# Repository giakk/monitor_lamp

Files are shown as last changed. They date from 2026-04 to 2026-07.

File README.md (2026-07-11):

# Monitor Light Bar

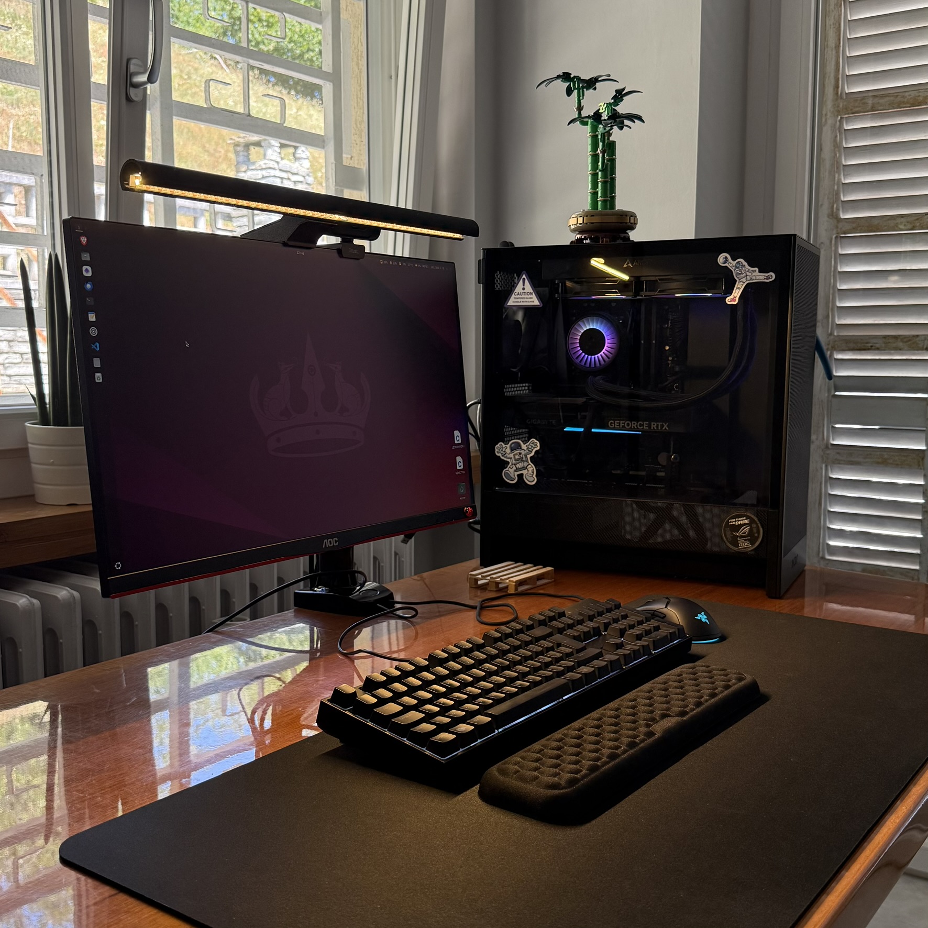
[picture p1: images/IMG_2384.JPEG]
overview
      

## Overview
I wanted a smart monitor bar without spending hundreds of euros for something like the BenQ monitor lamp, so I tried to DIY it. Everithing runs on an ESP32-C3 microcontroller, a bit overkill but it will be useful for future upgrade. To control the led, the ESP32 rely on two sensors: a VELM7700 luminosity sensor to dynamically adjusts the leds brightness to maintain optimal lighting conditions, and a LD2410 presense sensor to automatically activates when a user sits.

## 3D Design

## Electronics
The system is powered by a 12V input managed via a USB-C Power Delivery (PD) controller, which negotiate with the power supply to ensures 12V for the leds strips. A Mini360 step-down converter reduces this voltage to 5V to power the ESP32-C3 and the sensors, while a dedicated 1.25A fuse protects the entire circuit. The light engine consists of a 12V LED strip driven by an IRLZ44N MOSFET, which allows for precise PWM dimming controlled by the ESP32.

The "intelligence" of the hardware relies on two main modules: an LD2410 presence sensor connected via UART and a VEML7700 ambient light sensor communicating through the I2C protocol. 
The current prototype, as shown in the images below was updated with the new custom developed PCB board, which info can be found in the Kicad project. (Yeah, I know it is overkill but why no? I wanted to learn to use Kicad and develop my first PCB)

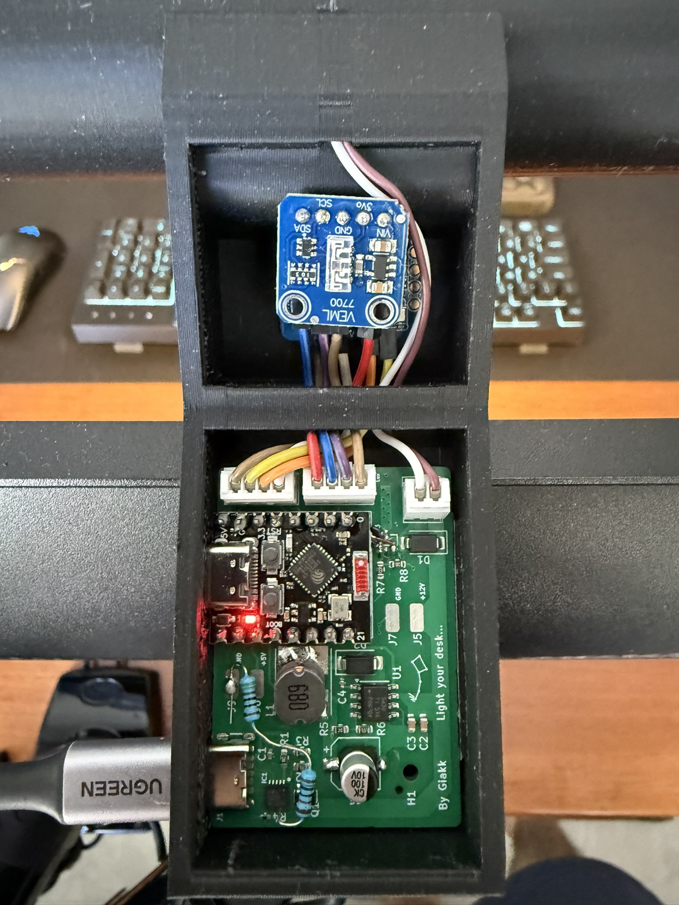
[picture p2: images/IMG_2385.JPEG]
Front
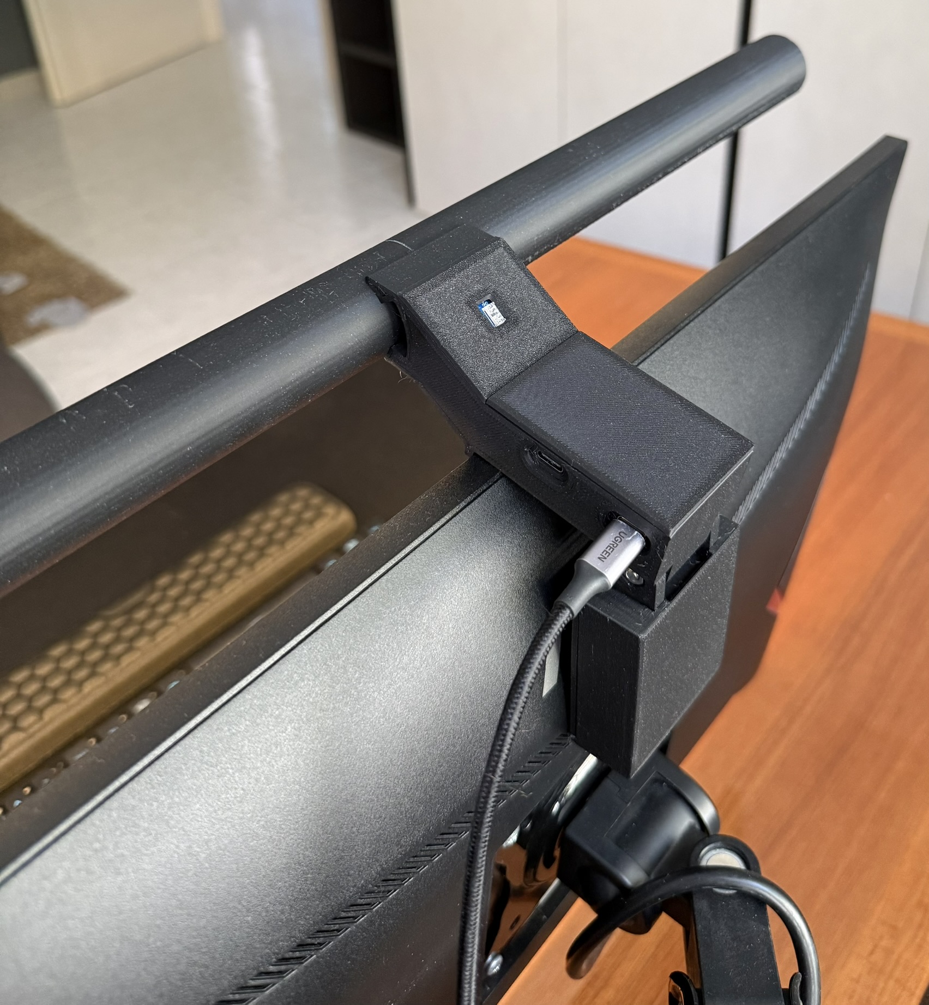
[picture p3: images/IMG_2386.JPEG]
Back
|  |  |
|:---:|:---:|

The board has been tested and corrected due to two mistakes I made in the eletrical scheme. First, I hadn't included the ISET resistor for the PD controller, which is essential for negotiating the correct voltage with the charger. Second, I had swapped the drain and source pins of the Q3 MOSFET. Now that everything works as expected, the board project should be correct I you want to produce it.

## Code
The firmware is developed within the Arduino framework and utilizes a non-blocking logic to monitor environmental changes in real-time. The core functionality revolves around an adaptive dimming algorithm: the system reads the ambient lux levels via the VEML7700 and applies a square root function to calculate the ideal LED duty cycle. This function actually work like the luminosity on the phone, so it increase if the lux of the room are high, while decrease if there is not light in the room. Maybe it is counterintuitive but it works for me. Change it as you want. 
To prevent annoying flickering or constant micro-adjustments, the code implements a hysteresis logic, only triggering a brightness transition if the change in light is significant. Furthermore, the integration with the LD2410 mmWave radar allows the lamp to manage power efficiently, executing smooth fade-in and fade-out transitions whenever a user enters or leaves the desk area, ensuring the light is only active when actually needed.
    
I am working on a version of the software which expose a web page to interact with the light in real time. In the meantime, I uploaded the version of the sketch that actually works the best, with is the `sketch_monitor_lamp_working.ino`

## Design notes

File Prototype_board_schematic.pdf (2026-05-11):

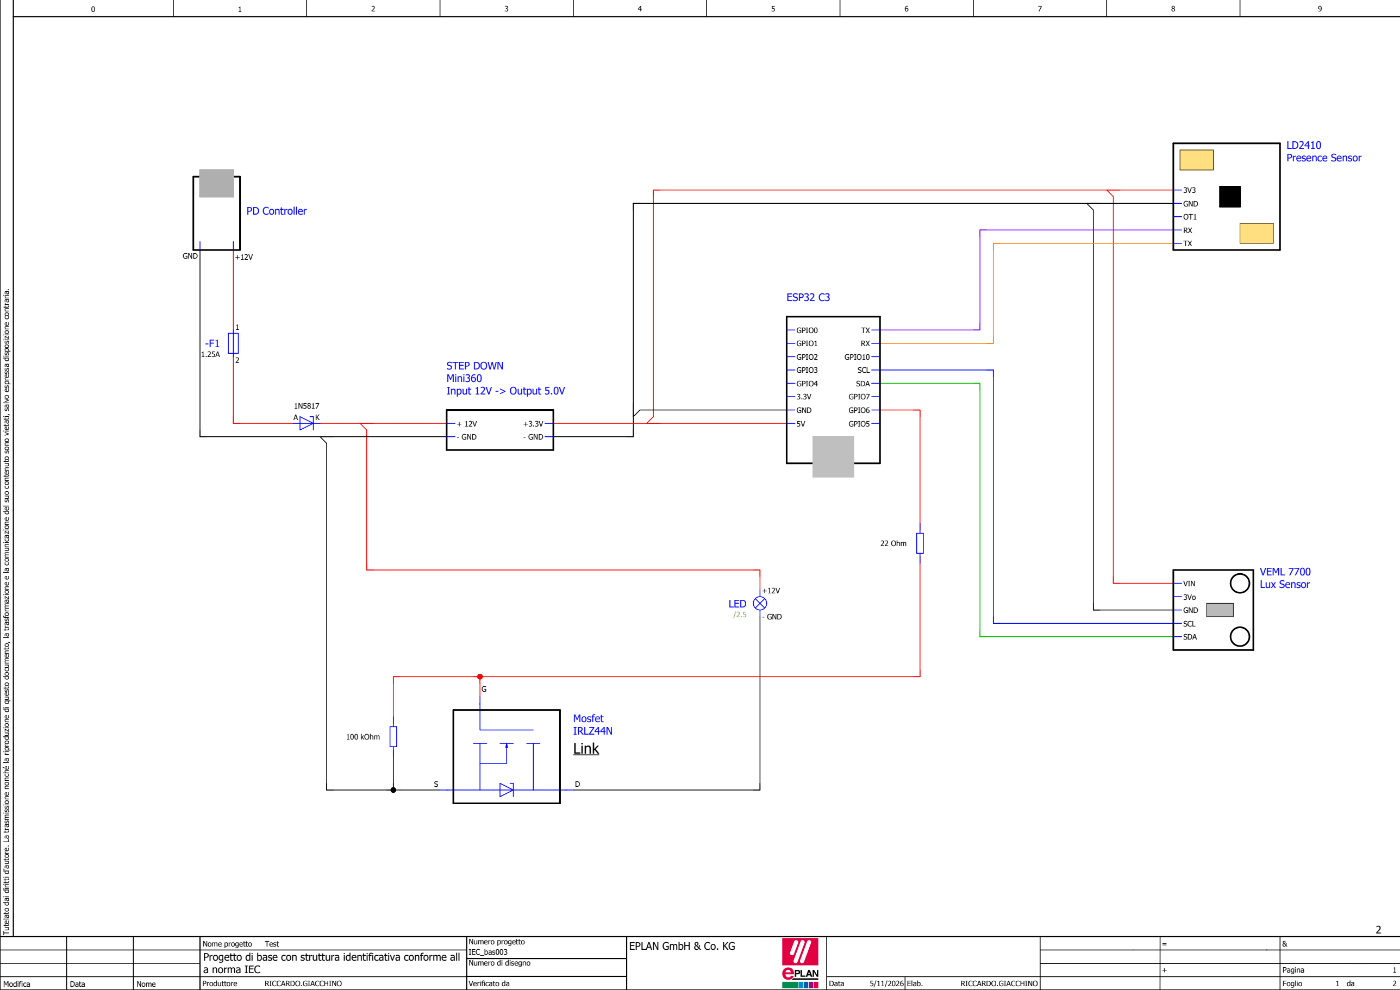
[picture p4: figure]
Foglio; a norma IEC; Elab.; IEC_bas003; Data; RICCARDO.GIACCHINO 1; Modifica; Nome; EPLAN GmbH & Co. KG; Pagina; Test; Verificato da; Nome progetto; Numero di disegno; Numero progetto; Produttore; RICCARDO.GIACCHINO; STEP DOWN Mini360 Input 12V -> Output 5.0V; ESP32 C3; VEML 7700 Lux Sensor; LD2410 Presence Sensor; Mosfet IRLZ44N Link; PD Controller; GND; GPIO4; GPIO3; GPIO2; GPIO1; GPIO0; GPIO10; SCL; SDA; GPIO7; GPIO6; GPIO5; - GND; LED; VIN; 22 Ohm; 100 kOhm

## Progetto di base con struttura identificativa conforme all

Tutelato dai diritti d'autore. La trasmissione nonché la riproduzione di questo documento, la trasformazione e la comunicazione del suo contenuto sono vietati, salvo espressa disposizione contraria.

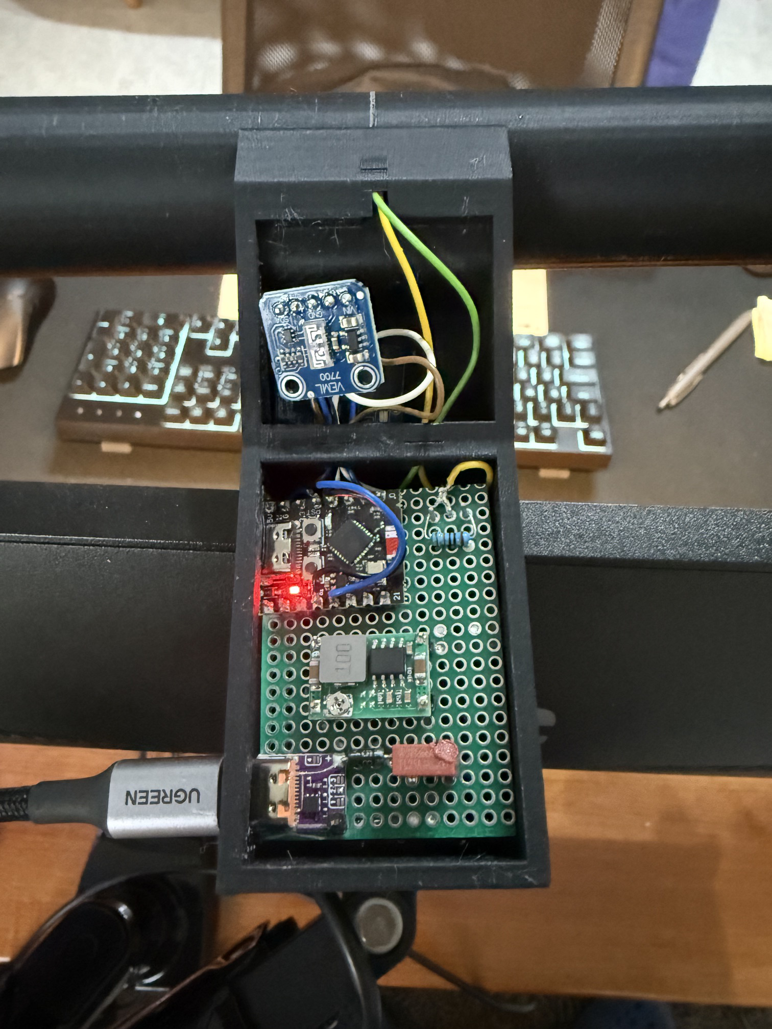
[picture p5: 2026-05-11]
images/proto_front.jpeg

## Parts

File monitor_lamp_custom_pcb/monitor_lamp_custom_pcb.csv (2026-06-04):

Reference | Value | Footprint | LCSC
C1 | 1µF | Capacitor_SMD:C_0402_1005Metric | C52923
C2 | 10uF | Capacitor_SMD:C_0603_1608Metric | C96446
C3 | 10uF | Capacitor_SMD:C_0603_1608Metric | C96446
C4 | 10nF | Capacitor_SMD:C_0402_1005Metric | C15195
D1 | SS34 | Diode_SMD:D_SMA | C8678
D2 | SS14 | Diode_SMD:D_SMA | C2480
IC1 | HUSB238 | Custom_Components:DFN-10L | C7471904
J1 | USB_C_Receptacle_PowerOnly_6P | Connector_USB:USB_C_Receptacle_GCT_USB4125-xx-x_6P_TopMnt_Horizontal | C283540
J5 | Conn_01x01 | Connector_Wire:SolderWirePad_1x01_SMD_2x4mm
J7 | Conn_01x01 | Connector_Wire:SolderWirePad_1x01_SMD_2x4mm
J8 | Conn_01x01 | Connector_Wire:SolderWirePad_1x01_SMD_2x4mm
J9 | Conn_01x01 | Connector_Wire:SolderWirePad_1x01_SMD_2x4mm
Q1 | AO3401A | Package_TO_SOT_SMD:SOT-23 | C15127
Q2 | AO3401A | Package_TO_SOT_SMD:SOT-23 | C15127
Q3 | AO3400A | Package_TO_SOT_SMD:SOT-23 | C20917
R1 | 10 | Resistor_SMD:R_0603_1608Metric | C22859
R2 | 5.1k | Resistor_SMD:R_0603_1608Metric | C23186
R3 | 49.9k | Resistor_SMD:R_0603_1608Metric | C23184
R4 | 10k | Resistor_SMD:R_0402_1005Metric | C25744
R5 | 10k | Resistor_SMD:R_0603_1608Metric | C25804
R6 | 3.3k | Resistor_SMD:R_0603_1608Metric | C22978
R7 | 22 | Resistor_SMD:R_0603_1608Metric | C23345
R8 | 100k | Resistor_SMD:R_0603_1608Metric | C25803
U1 | TPS5430DDA | Package_SO:TI_SO-PowerPAD-8_ThermalVias | C9864

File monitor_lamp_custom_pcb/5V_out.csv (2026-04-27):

Part | Value | Part Number Suggested | LCSC JLCPCB Library | Quantity | Description | 15V → 5V
L1 | 68 µH | VLP8040T-470M | Aliexpres | 1 | L: 68 µH DCR: 160 mΩ IDC: 1.5 A
U1 | Regulator | TPS5430DDAR | C9864 | 1
Cout | 100 uF | TPSD157M010R0100 | Aliexpres | 1 | Cap: 100 µF Total Derated Cap: 150 µF VDC: 10 V ESR: 100 mΩ Package: D
D1 |  | SS14FL | C2480 | 1 | Type: Schottky VRRM: 40 V Io: 1 A
Cin | 10 uF | MSAST21GBB5106MTNA01 | C96446 | 2 | Cap: 10 µF Total Derated Cap: 5.6 µF VDC: 25 V ESR: 5.46 mΩ Package: 0805
Rfbb | 3.3kO | CRCW04023K24FKED | C22978 | 1 | Resistance: 3.24 kΩ Tolerance: 1.0% Power: 63 mW
Rfbt | 10kO | RC0201FR-0710KL | C25804 | 1 | Resistance: 10 kΩ Tolerance: 1.0% Power: 50 mW
Cboot | 10 nF | GRM155R71H103KA88D | C15195 | 1 | Cap: 10 nF Total Derated Cap: 10 nF VDC: 50 V ESR: 1 mΩ Package: 0402
Part | Value | Part Number Suggested | LCSC JLCPCB Library | Quantity | Description | 15V → 12V
L1 | 22 µH | NPI34W220MTRF | Aliexpres | 1 | L: 22 µH DCR: 66 mΩ IDC: 2.9 A
U1 | Regulator | TPS5430DDAR | C9864 | 1
Cout | 100 µF | TPSD107K020R0085 | Aliexpres | 1 | Cap: 100 µF Total Derated Cap: 100 µF VDC: 20 V ESR: 85 mΩ Package: D
D1 |  | SS14FL | C2480 | 1 | Type: Schottky VRRM: 40 V Io: 1 A
Cin | 22 µF | GRM32ER61E226KE15L | C59461 | 2 | Cap: 22 µF Total Derated Cap: 16 µF VDC: 25 V ESR: 2 mΩ Package: 1210
Rfbb | 1.1kO | CRCW04021K13FKED | C22764 | 1 | Resistance: 1.13 kΩ Tolerance: 1.0% Power: 63 mW
Rfbt | 10kO | RC0201FR-0710KL | C25804 | 1 | Resistance: 10 kΩ Tolerance: 1.0% Power: 50 mW
Cboot | 10 nF | GRM155R71H103KA88D | C15195 | 1 | Cap: 10 nF Total Derated Cap: 10 nF VDC: 50 V ESR: 1 mΩ Package: 0402

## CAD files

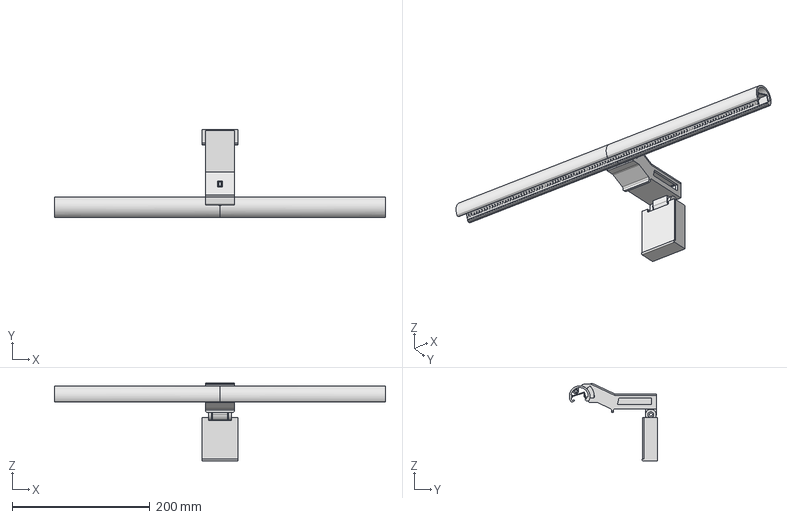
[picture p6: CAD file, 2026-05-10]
3d models/model_almost_done.step
480.0 x 128.3 x 112.6 mm
Barra v36
Barra v36(Mirror)
Shaft
Cap
lower support
Cover1
Cover2
Cover3
Blocco
barretta
ComponentsPlacement
barraledstriscia
Adafruit VEML 7700 Light Sensor Breakout Board

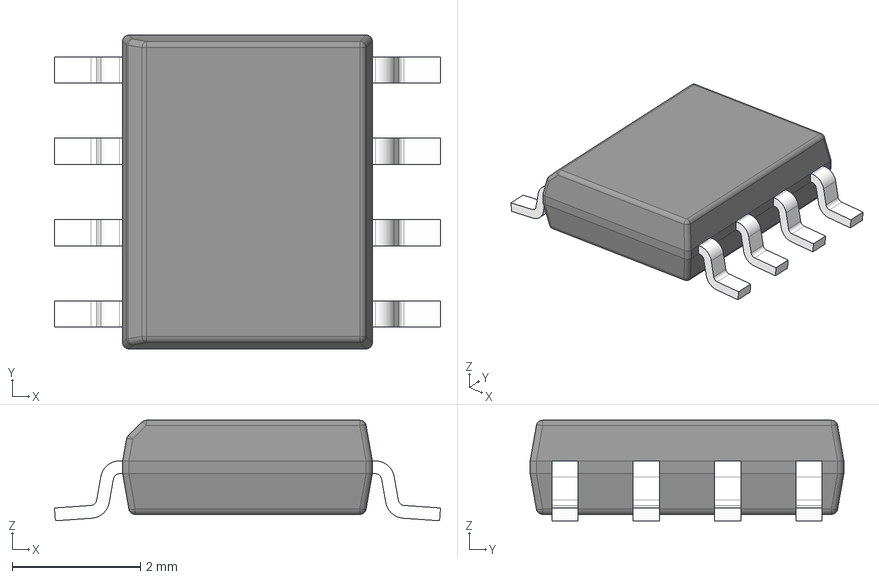
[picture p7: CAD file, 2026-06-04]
monitor_lamp_custom_pcb/3d models/DDA0008B.stp
6.03 x 4.90 x 1.57 mm
BODY-SO
LEAD-SO x 8
THERMALPAD-SO

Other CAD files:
3d models/model_almost_done.f3z

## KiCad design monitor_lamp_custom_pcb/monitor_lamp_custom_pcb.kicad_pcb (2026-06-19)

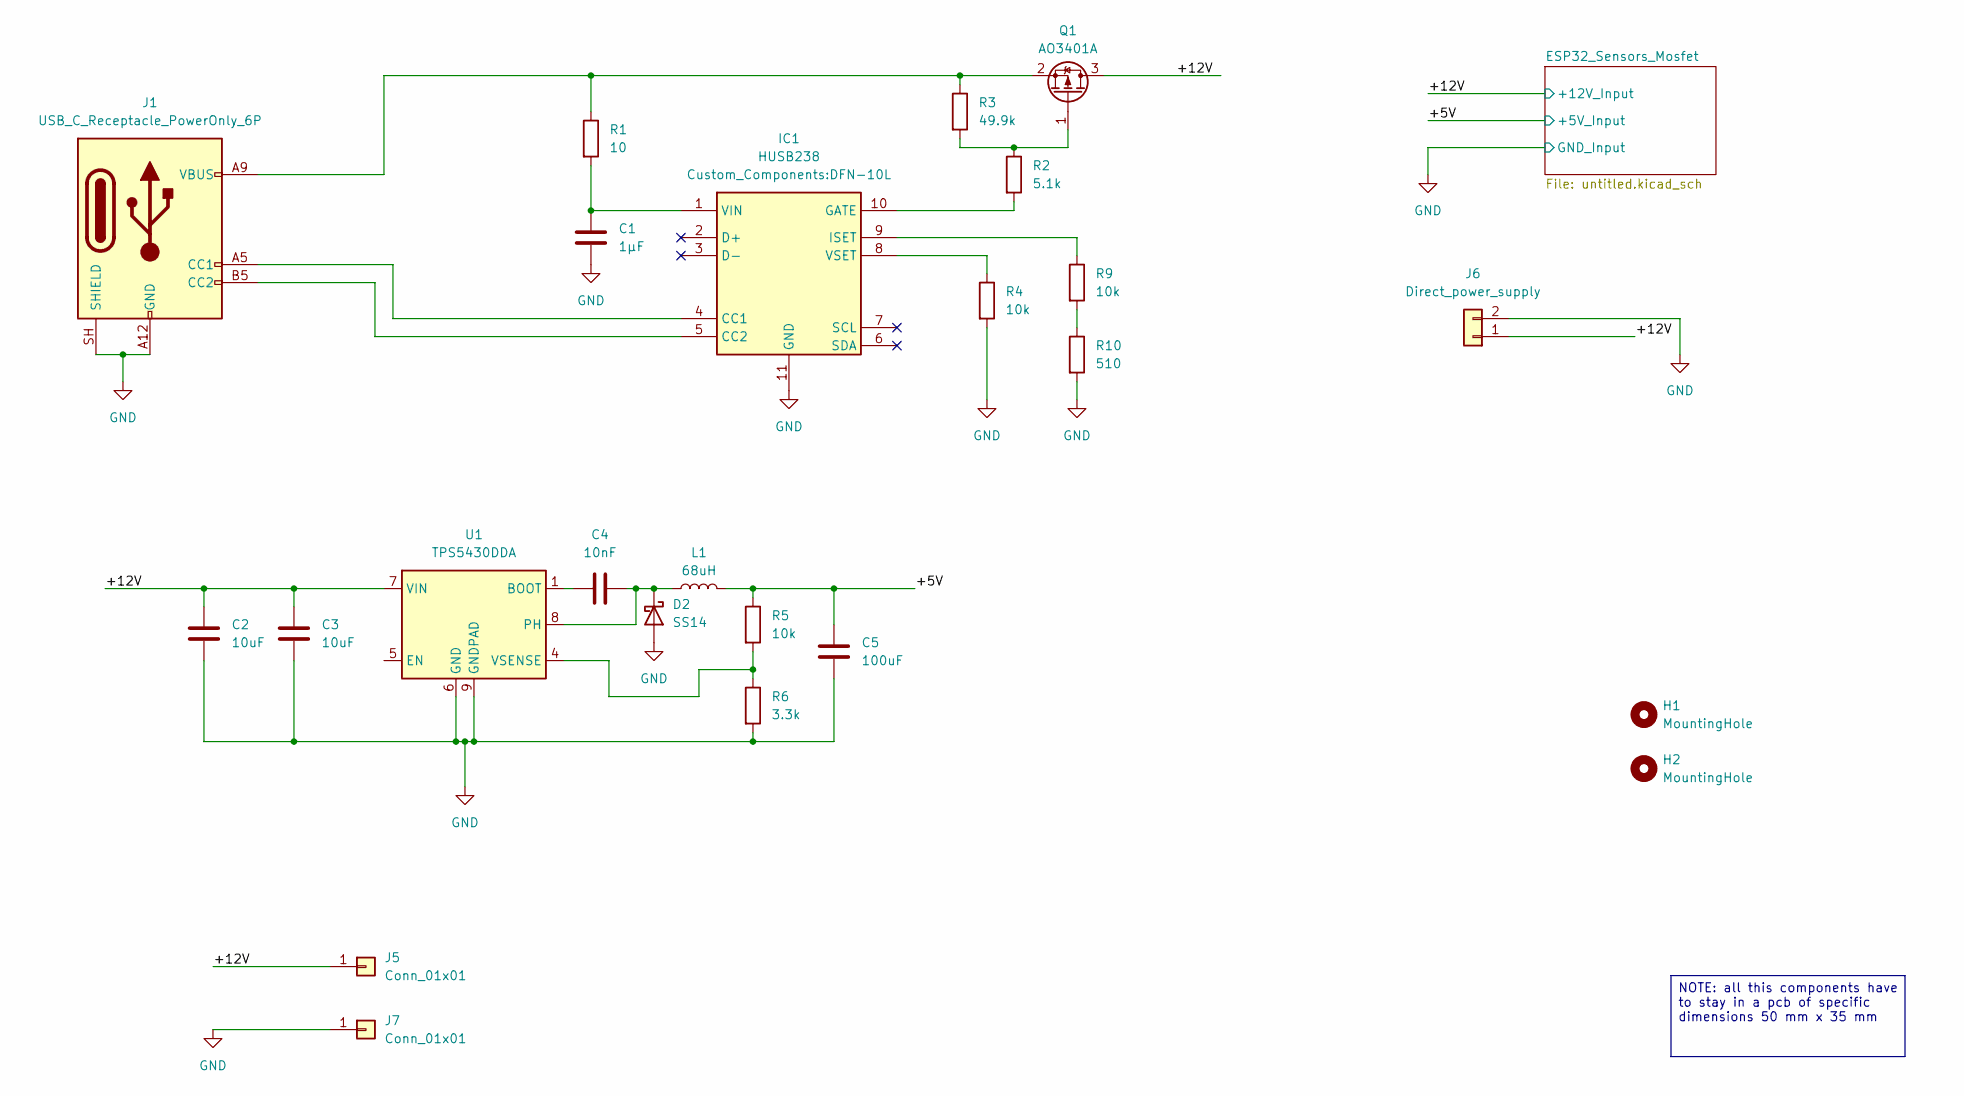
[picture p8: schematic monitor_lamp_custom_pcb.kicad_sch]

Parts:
C1: 1µF; C_0402_1005Metric; LCSC C52923
C2, C3: 10uF; C_0603_1608Metric; LCSC C96446
C4: 10nF; C_0402_1005Metric; LCSC C15195
C5: 100uF; CP_Elec_5x5.4
D2: SS14; D_SMA; LCSC C2480
H1, H2: MountingHole; MountingHole_2.2mm_M2
IC1: HUSB238; DFN-10L; Manufacturer_Part_Number HUSB238; LCSC C7471904
J1: USB_C_Receptacle_PowerOnly_6P; USB_C_Receptacle_GCT_USB4125-xx-x_6P_TopMnt_Horizontal; LCSC C283540
J5, J7: Conn_01x01; SolderWirePad_1x01_SMD_1.5x3mm
J6: Direct_power_supply
L1: 68uH; L_Sumida_CD75
Q1: AO3401A; SOT-23; LCSC C15127
R1: 10; R_0603_1608Metric; LCSC C22859
R2: 5.1k; R_0603_1608Metric; LCSC C23186
R3: 49.9k; R_0603_1608Metric; LCSC C23184
R4, R9: 10k; R_0402_1005Metric; LCSC C25744
R5: 10k; R_0603_1608Metric; LCSC C25804
R6: 3.3k; R_0603_1608Metric; LCSC C22978
R10: 510; R_0402_1005Metric; LCSC C25123
U1: TPS5430DDA; TI_SO-PowerPAD-8_ThermalVias; LCSC C9864

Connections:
/+5V: C5.1, L1.2, R5.1; also elsewhere on the board
/+12V: C2.1, C3.1, J5.1 (Pin_1_1), J6.1, Q1.3 (D), U1.7 (VIN); also elsewhere on the board
GND: C1.2, C2.2, C3.2, C5.2, D2.2 (A), IC1.11 (GND), J1.A12 (GND), J1.B12 (GND), J1.SH (SHIELD), J6.2, J7.1 (Pin_1_1), R4.2, R6.2, R10.2, U1.6 (GND), U1.9 (GNDPAD); also elsewhere on the board
unnamed: C4.2, D2.1 (K), L1.1, U1.8 (PH)
unnamed: IC1.4 (CC1), J1.A5 (CC1)
unnamed: IC1.5 (CC2), J1.B5 (CC2)
unnamed: IC1.10 (GATE), R2.2
unnamed: IC1.9 (ISET), R9.1
unnamed: C1.1, IC1.1 (VIN), R1.2
unnamed: IC1.8 (VSET), R4.1
unnamed: Q1.1 (G), R2.1, R3.2
unnamed: J1.A9 (VBUS), J1.B9 (VBUS), Q1.2 (S), R1.1, R3.1
unnamed: R9.2, R10.1
unnamed: C4.1, U1.1 (BOOT)
unnamed: R5.2, R6.1, U1.4 (VSENSE)

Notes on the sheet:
NOTE: all this components have to stay in a pcb of specific dimensions 50 mm x 35 mm

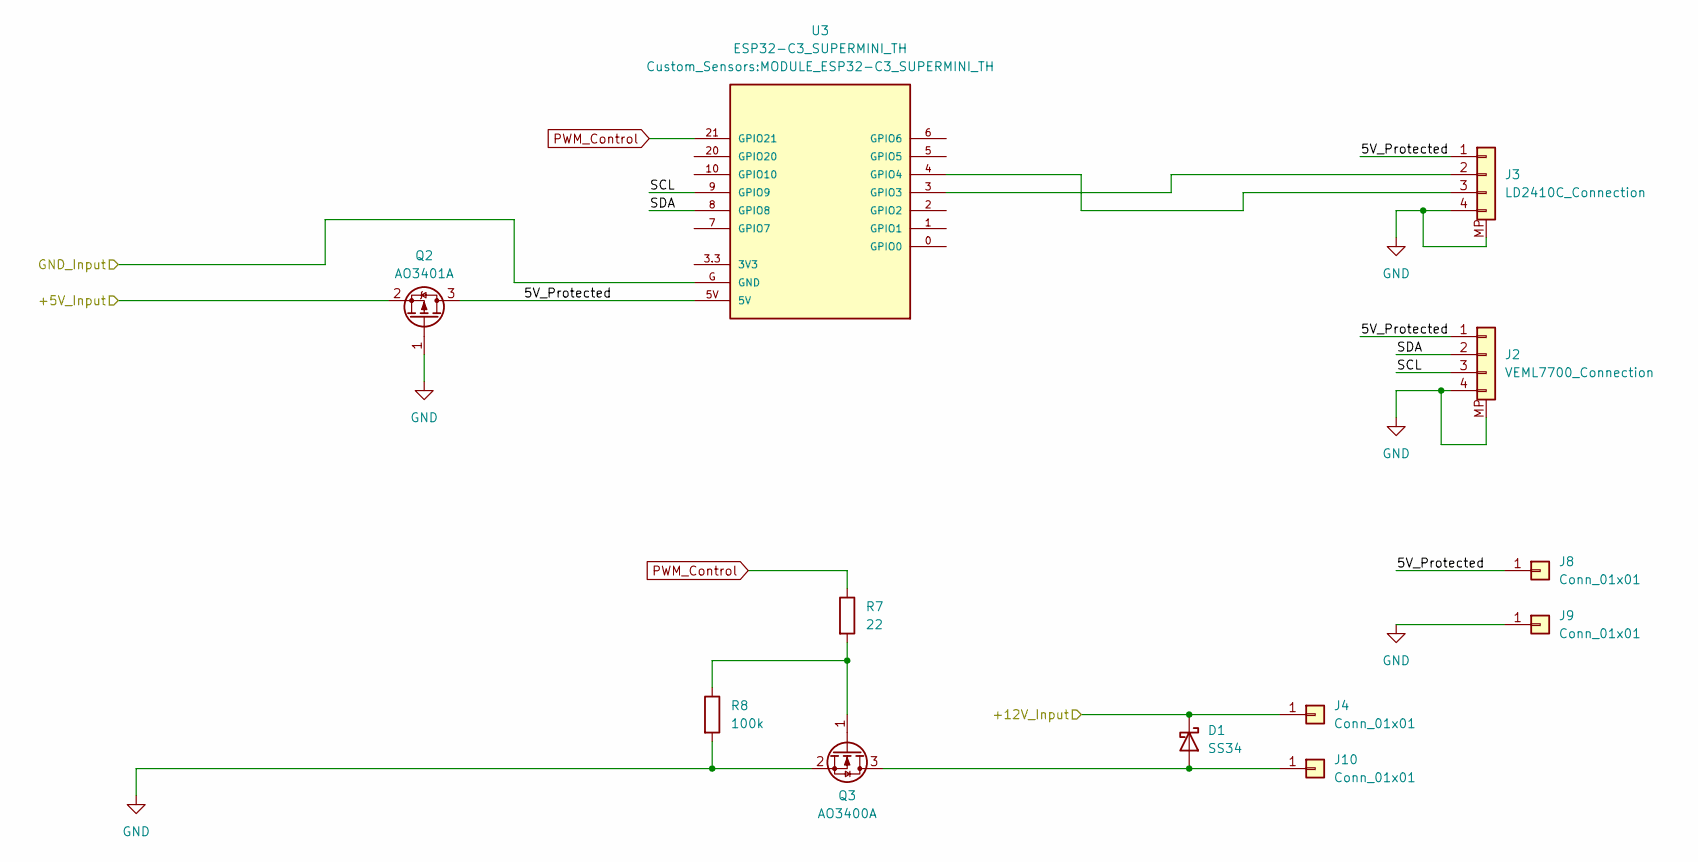
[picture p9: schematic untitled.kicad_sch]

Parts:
D1: SS34; D_SMA; LCSC C8678
J2: VEML7700_Connection; JST_PH_B4B-PH-K_1x04_P2.00mm_Vertical
J3: LD2410C_Connection; JST_PH_B4B-PH-K_1x04_P2.00mm_Vertical
J4, J8, J9, J10: Conn_01x01; SolderWirePad_1x01_SMD_1.5x3mm
Q2: AO3401A; SOT-23; LCSC C15127
Q3: AO3400A; SOT-23; LCSC C20917
R7: 22; R_0603_1608Metric; LCSC C23345
R8: 100k; R_0603_1608Metric; LCSC C25803
U3: ESP32-C3_SUPERMINI_TH; MODULE_ESP32-C3_SUPERMINI_TH

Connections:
/+5V: Q2.2 (S); also elsewhere on the board
/+12V: D1.1 (K), J4.1 (Pin_1_1); also elsewhere on the board
/ESP32_Sensors_Mosfet/5V_Protected: J2.1, J3.1, J8.1 (Pin_1_1), Q2.3 (D), U3.5V
/ESP32_Sensors_Mosfet/SCL: J2.3, U3.9 (GPIO9)
/ESP32_Sensors_Mosfet/SDA: J2.2, U3.8 (GPIO8)
GND: J2.4, J2.MP, J3.4, J3.MP, J9.1 (Pin_1_1), Q2.1 (G), Q3.2 (S), R8.2, U3.G (GND); also elsewhere on the board
unnamed: D1.2 (A), J10.1 (Pin_1_1), Q3.3 (D)
unnamed: J3.2, U3.3 (GPIO3)
unnamed: J3.3, U3.4 (GPIO4)
unnamed: Q3.1 (G), R7.2, R8.1
PWM_Control: R7.1, U3.21 (GPIO21)

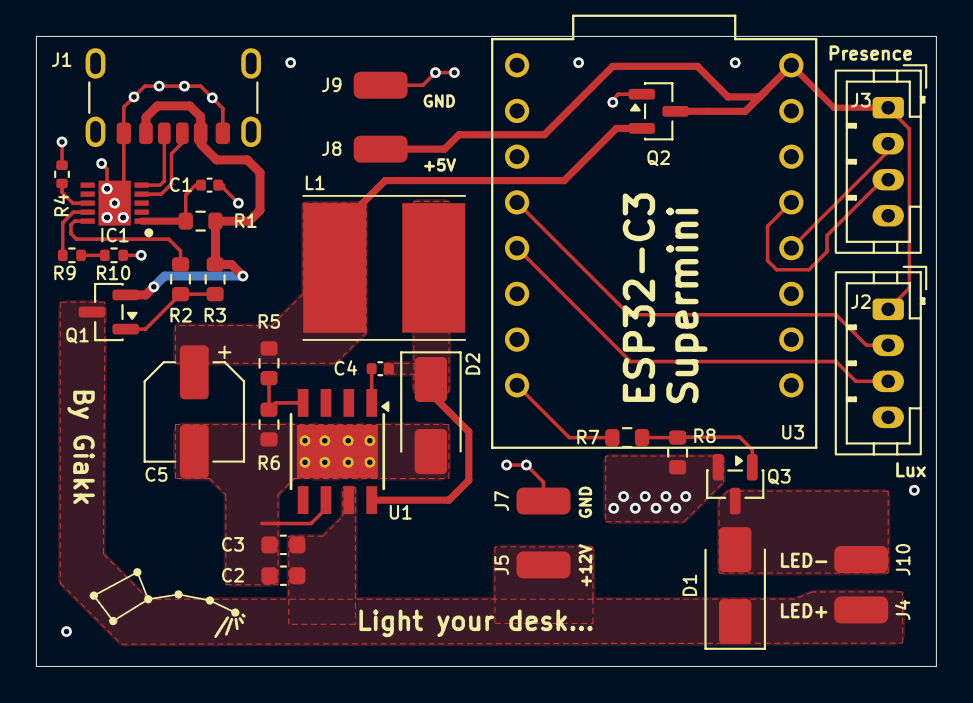
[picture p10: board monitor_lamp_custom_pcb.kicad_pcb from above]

Board: 2 copper layers, 50.0 x 35.0 mm, 35 parts (0 on the bottom side), 23 nets.

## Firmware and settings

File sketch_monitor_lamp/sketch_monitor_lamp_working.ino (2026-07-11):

/*

THIS FILE IS THE FIRST PROJECT AND WORKS. IT IS HERE AS A BACKUP IN CASE YOU NEED SOMETHING THAT JUST WORKS

#include "7Semi_VEML7700.h"
#include "driver/ledc.h"
#include "MyLD2410.h"
#include "esp_err.h"
#include "esp_log.h" // For ESP_LOGx


// I2C settings
#define I2C_ADDRESS 0x10
#define I2C_CLOCK 400000
#define I2C_PORT I2C_NUM_0
#define I2C_SDA_PIN 8
#define I2C_SCL_PIN 9

// PWM settings
#define LEDC_TIMER      LEDC_TIMER_0
#define LEDC_MODE       LEDC_LOW_SPEED_MODE
#define LEDC_CHANNEL    LEDC_CHANNEL_0
#define LEDC_GPIO       21
#define LEDC_FREQ_HZ    19000
#define LEDC_RESOLUTION LEDC_TIMER_12_BIT
#define LEDC_START_DUTY  (0)
#define LEDC_TARGET_DUTY (4095)
#define FADE_TIME_MS   (1000)

// UART LD2410C settings
#define TX_PIN 4
#define RX_PIN 3
#define NO_ONE_WINDOW_S 1

// ── Metti true per eseguire l'autocalibrazione all'avvio ──
#define AUTO_THRESHOLD false
#define AUTO_THRESHOLD_TIMEOUT_S 10  // secondi per uscire dalla stanza

#define REFRESH_RATE 100 //millisec

VEML7700_7Semi light;

HardwareSerial radarSerial(1); // UART1
MyLD2410 radar(radarSerial);
uint32_t currentDuty = 0;
uint32_t targetDuty = 0; 
uint32_t fadeStep = 10;

bool fade_ended = false;  // status of LED fade
bool fade_in = true;

int parabolicFunction(float lux);
int line(float lux);
int sqrtFunction(float lux);

void setup() {

  Serial.begin(115200);

  // VEML7700 Initialization
  light.begin(I2C_ADDRESS, Wire, I2C_CLOCK, I2C_SDA_PIN, I2C_SCL_PIN);

  // VEML7700 Configuration
  light.setGain(VEML7700_GAIN_2);
  light.setIntegrationTime(VEML7700_IT_100MS);
  light.setPowerMode(VEML7700_PSM_MODE2, true);

  // PWM Initialization
  ledc_timer_config_t timer_conf = {
    .speed_mode      = LEDC_MODE,
    .duty_resolution = LEDC_RESOLUTION,
    .timer_num       = LEDC_TIMER,
    .freq_hz         = LEDC_FREQ_HZ,
    .clk_cfg         = LEDC_AUTO_CLK,
  };
  ledc_timer_config(&timer_conf);

  ledc_channel_config_t channel_conf = {
    .gpio_num   = LEDC_GPIO,
    .speed_mode = LEDC_MODE,
    .channel    = LEDC_CHANNEL,
    .timer_sel  = LEDC_TIMER,
    .duty       = 0,
    .hpoint     = 0,
  };
  ledc_channel_config(&channel_conf);

  // Installa il servizio fade LEDC (chiamare UNA SOLA VOLTA nel setup!)
  ledc_fade_func_install(0);

  // LD2410 Initialization
  radarSerial.begin(LD2410_BAUD_RATE, SERIAL_8N1, RX_PIN, TX_PIN);
  if (radar.begin()) {
    //Serial.println("LD2410 inizializzato");
  } else {
    Serial.println("LD2410 non risponde");
  }

  //radar.setResolution(true);  //true to set resolution 'fine' (20cm)
  //radar.setNoOneWindow(NO_ONE_WINDOW_S);
  // delay(1000);
  // radar.configMode(true); // enter configuration mode
  // radar.setGateParameters(0, 100, 100);
  // radar.setGateParameters(1, 100, 100);
  // radar.setGateParameters(2, 45, 45);
  // radar.setGateParameters(3, 25, 25);
  // radar.setGateParameters(4, 25, 25);
  // radar.setGateParameters(5, 60, 60);
  // radar.setGateParameters(6, 100, 100);
  // radar.setMaxGate(5, 5, 1);

  // const MyLD2410::ValuesArray& mov = radar.getMovingThresholds();
  // Serial.println("Moving thresholds:");
  // for (byte i = 0; i <= mov.N; i++) {
  //   Serial.printf("  Gate %d: %d\n", i, mov.values[i]);
  // }

  // const MyLD2410::ValuesArray& sta = radar.getStationaryThresholds();
  // Serial.println("Stationary thresholds:");
  // for (byte i = 0; i <= sta.N; i++) {
  //   Serial.printf("  Gate %d: %d\n", i, sta.values[i]);
  // }

  // Serial.println(radar.getResolution());

  // //radar.requestBToff();
  // radar.configMode(false);
  // delay(500);
}




void loop() {
  float lux = 0;

  if (radar.check() == MyLD2410::Response::DATA) {
    if (light.readLux(lux)) {
      lux = int(lux);

      bool presence = radar.presenceDetected();

      Serial.print("Ambient light: ");
      Serial.print(lux);
      Serial.print(" | Presenza: ");
      Serial.print(presence ? "SI | " : "NOooooooooooooooo | ");
      Serial.printf("Distanza: %lu cm\n", radar.detectedDistance());

      uint32_t pwm_target = uint32_t(presence ? sqrtFunction(lux) : 0);
      uint32_t current_duty = ledc_get_duty(LEDC_MODE, LEDC_CHANNEL);

      // Isteresi: riavvia il fade solo se la differenza è significativa
      const uint32_t HYSTERESIS = 50;
      if (abs((int)current_duty - (int)pwm_target) > HYSTERESIS) {

        // Velocità proporzionale: fade_ms è proporzionale alla distanza da percorrere
        uint32_t delta = abs((int)pwm_target - (int)current_duty);
        uint32_t fade_ms = map(delta, 0, (1 << LEDC_TIMER_12_BIT) - 1, 0, FADE_TIME_MS);

        ledc_fade_func_uninstall();
        ledc_fade_func_install(0);

        ledc_set_fade_with_time(LEDC_MODE, LEDC_CHANNEL, pwm_target, fade_ms);
        ledc_fade_start(LEDC_MODE, LEDC_CHANNEL, LEDC_FADE_NO_WAIT);
      }

    } else {
      Serial.println("Failed to read lux");
    }
  }
}

int luxToDuty(float lux, float lux_max = 500.0f, float gamma = 2.2f) {
  const int max_duty = (1 << LEDC_TIMER_12_BIT) - 1;

  // 1. Normalizza lux in [0.0, 1.0]
  float normalized = constrain(lux / lux_max, 0.0f, 1.0f);

  // 2. Gamma correction: più lux c'è, MENO luce vogliamo dal LED
  //    Invertiamo: con tanta luce ambientale il LED si abbassa
  float inverted = 1.0f - normalized;

  // 3. Applica gamma (percettivamente lineare)
  float corrected = pow(inverted, gamma);

  return (int)(corrected * max_duty);
}

int sqrtFunction(float lux) {
  // Clamp: lux oltre 150 supererebbe 4095

  const int max_duty = (1 << LEDC_TIMER_12_BIT) - 1; // = 4095

  if (lux >= 400.0f) return max_duty;
  if (lux <= 0.0f)   return 0;
  int val = (int)(sqrt(lux / 400.0f) * max_duty);
  // Sicurezza extra
  return constrain(val, 0, max_duty);
}

*/

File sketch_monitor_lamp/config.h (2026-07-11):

#pragma once

// ESP32 setup variables.

// ── I2C (VEML7700) ────────────────────────────────────────────────────────────
#define I2C_ADDRESS 0x10
#define I2C_CLOCK 400000
#define I2C_PORT I2C_NUM_0
#define I2C_SDA_PIN 8
#define I2C_SCL_PIN 9

// ── PWM (LED strip) ───────────────────────────────────────────────────────────
#define LEDC_GPIO       21
#define LEDC_FREQ_HZ    5000
#define LEDC_RESOLUTION LEDC_TIMER_12_BIT
#define LEDC_MAX_DUTY   ((1 << LEDC_RESOLUTION) - 1)

// ── UART (LD2410C) ────────────────────────────────────────────────────────────
#define TX_PIN 4
#define RX_PIN 3
#define NO_ONE_WINDOW_S 1

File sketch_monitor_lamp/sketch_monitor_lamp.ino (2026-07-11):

#include "config.h"
#include "config_manager.h"
#include "sensors.h"
#include "lamp_control.h"
#include "wifi_manager.h"
#include "web_server.h"
#include "esp_system.h"
#include <LittleFS.h>

static unsigned long lastSensorUpdate = 0;

void setup() {
  
Serial.begin(115200);
  delay(500);
  Serial.println("\n[boot] Monitor Lamp starting...");

  if (!LittleFS.begin(true)) {
    Serial.println("[boot] LittleFS mount failed");
  }  
  
  config_init();
  sensors_init();
  lamp_init();
  wifi_connect();
  webserver_init();
  Serial.println("[boot] Ready.");

}

void loop() {
  unsigned long now = millis();

  if (now - lastSensorUpdate >= config_get().refresh_rate_ms) {
    lastSensorUpdate = now;

    SensorData data = sensors_read();
    lamp_update(data);
    webserver_update_sensors(data);
  }
}

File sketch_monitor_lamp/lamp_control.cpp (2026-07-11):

#include "lamp_control.h";

static bool lamp_is_on = true;
static LampMode lamp_mode = LampMode::AUTO;
static const AppConfig* cfg = nullptr;
static uint8_t s_brightness = 100;

void lamp_init(){
    ledcAttach(LEDC_GPIO, LEDC_FREQ_HZ, LEDC_RESOLUTION);
    ledcWrite(LEDC_GPIO, 0);
    cfg = &config_get();
}

void lamp_update(const SensorData& data){

    uint32_t current_duty = ledcRead(LEDC_GPIO);
    uint32_t pwm_target;

    if (!lamp_is_on || !data.presence) {
        pwm_target = 0;
    } else if (lamp_mode == LampMode::MANUAL) {
        pwm_target = percent_to_duty(s_brightness);
    } else {
        pwm_target = 0;
        if (data.radar_ok && data.lux_ok) {
            pwm_target = data.presence ? uint32_t(sqrtFunction(data.lux)) : 0;
        }
    }

    if (abs((int)current_duty - (int)pwm_target) > cfg->pwm_hysteresis) {
        uint32_t delta = abs((int)pwm_target - (int)current_duty);
        uint32_t fade_ms = map(delta, 0, LEDC_MAX_DUTY, 0, cfg->fade_time_ms);
        ledcFade(LEDC_GPIO, current_duty, pwm_target, fade_ms);
    }
}

// _ Helper functions ___________________________________________________

int sqrtFunction(float lux) {
  
    if (lux >= cfg->lux_max) 
        return LEDC_MAX_DUTY;

    if (lux <= 0.0f)
        return 0;

    int val = (int)(sqrt(lux / cfg->lux_max) * LEDC_MAX_DUTY);

    return constrain(val, 0, LEDC_MAX_DUTY);
}

uint32_t percent_to_duty(uint8_t pct) {
    return (uint32_t)map(constrain(pct, 0, 100), 0, 100, 0, LEDC_MAX_DUTY);
}

void lamp_set_brightness(uint8_t percent){
    s_brightness = constrain(percent, 0, 100);
}

uint8_t lamp_get_brightness(){
    return s_brightness;
}

void lamp_set_mode(LampMode mode){
    lamp_mode = mode;
}

LampMode lamp_get_mode(){
    return lamp_mode;
}

void lamp_set_on(bool set){
    lamp_is_on = set;
}
bool lamp_get_on(){
    return lamp_is_on;
}

uint32_t lamp_get_duty(){
    return ledcRead(LEDC_GPIO);
}

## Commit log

2026-04-17 implemented fade using ledc library function
    Smoother effect
2026-04-18 Added custom library component to the project
    In Kicad not all components are present in the default library, some sensors or modules have to be manually added importing symbols and footprint.
    Putting this components inside the project is useful so if someone will download it, in is not necessary to search and import the components
    [monitor_lamp_custom_pcb.kicad_pcb, monitor_lamp_custom_pcb.kicad_sch, untitled.kicad_sch]
2026-04-18 Started to place component in the pcb design.
    [monitor_lamp_custom_pcb.kicad_pcb, monitor_lamp_custom_pcb.kicad_sch, untitled.kicad_sch]
2026-04-19 Started to place components on the board layout
    [monitor_lamp_custom_pcb.kicad_pcb, monitor_lamp_custom_pcb.kicad_sch, untitled.kicad_sch]
2026-04-20 Added almost all components to the board. Next step trace
    [monitor_lamp_custom_pcb.kicad_pcb, monitor_lamp_custom_pcb.kicad_sch, untitled.kicad_sch]
2026-04-20 Placed all components, changed the J2 & J3 connectors
    [monitor_lamp_custom_pcb.kicad_pcb, untitled.kicad_sch]
2026-04-20 Modified layout and J2&J3 connectors
    [monitor_lamp_custom_pcb.kicad_pcb, monitor_lamp_custom_pcb.kicad_sch]
2026-04-20 Selected 4-Layer setup. Started to trace
    [monitor_lamp_custom_pcb.kicad_pcb, monitor_lamp_custom_pcb.kicad_sch]
2026-04-20 Tracing some routes
    [monitor_lamp_custom_pcb.kicad_pcb, untitled.kicad_sch]
2026-04-21 Trace all routes and zone on pcb
    [monitor_lamp_custom_pcb.kicad_pcb]
2026-04-21 Added GND via around pcb area
    [monitor_lamp_custom_pcb.kicad_pcb]
2026-04-21 Added connection for temp sensor
    [monitor_lamp_custom_pcb.kicad_pcb, untitled.kicad_sch]
2026-04-21 Added supplementary power supply connection
    [monitor_lamp_custom_pcb.kicad_pcb, monitor_lamp_custom_pcb.kicad_sch, untitled.kicad_sch]
2026-04-22 Some test
    [monitor_lamp_custom_pcb.kicad_pcb]
2026-04-23 Corrected position and writing of graphical layer
    [monitor_lamp_custom_pcb.kicad_pcb]
2026-04-24 Changed all resistors footprint to R_0603_1608 metric
    [monitor_lamp_custom_pcb.kicad_pcb, monitor_lamp_custom_pcb.kicad_sch, untitled.kicad_sch]
2026-04-24 Added some LCSC to the components
    [monitor_lamp_custom_pcb.kicad_pcb, monitor_lamp_custom_pcb.kicad_sch, untitled.kicad_sch]
2026-04-25 Assign LCSC number to some component and selected new voltage regulator
    [monitor_lamp_custom_pcb.kicad_sch, untitled.kicad_sch]
2026-04-27 Drastic change
    [5V_out.csv, monitor_lamp_custom_pcb.kicad_sch, untitled.kicad_sch]
2026-04-29 Remodelled the scheme with 12V input
    [DDA0008B.stp, monitor_lamp_custom_pcb.kicad_pcb, monitor_lamp_custom_pcb.kicad_sch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]
2026-05-06 Placed connection pad
    [monitor_lamp_custom_pcb.kicad_pcb, monitor_lamp_custom_pcb.kicad_sch, untitled.kicad_sch]
2026-05-06 Terminated design, generated fabrication files for JLCPCB
    [monitor_lamp_custom_pcb-B_Cu.gbl, monitor_lamp_custom_pcb-B_Mask.gbs, monitor_lamp_custom_pcb-B_Paste.gbp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]
2026-05-06 almost done
    [monitor_lamp_custom_pcb.kicad_pcb]
2026-05-07 Added some drawing to the board and recreated fabbrication file
    [monitor_lamp_custom_pcb-B_Cu.gbl, monitor_lamp_custom_pcb-B_Mask.gbs, monitor_lamp_custom_pcb-B_Paste.gbp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]
2026-05-07 Changed connector to JST PH 2.0mm
    [monitor_lamp_custom_pcb-B_Cu.gbl, monitor_lamp_custom_pcb-B_Mask.gbs, monitor_lamp_custom_pcb-B_Paste.gbp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]
2026-05-08 Definitive version - Ordered on JLCPCB
    [monitor_lamp_custom_pcb-B_Cu.gbl, monitor_lamp_custom_pcb-B_Mask.gbs, monitor_lamp_custom_pcb-B_Paste.gbp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]
2026-05-10 Added step model of the lamp
    [model_almost_done.f3z, model_almost_done.step]
2026-05-11 Added proto board photos
2026-05-11 Added proto board circuit diagram
2026-05-22 Added ISET resistor for solving 12V issue on previous release
    [monitor_lamp_custom_pcb.kicad_pcb, monitor_lamp_custom_pcb.kicad_sch, untitled.kicad_sch]
2026-06-04 Corrected ISET pin error and changed to pads for connecting LED supply
    [monitor_lamp_custom_pcb.kicad_pcb, monitor_lamp_custom_pcb.kicad_sch, untitled.kicad_sch]
2026-06-04 Simplified ESP32 sketch (TO BE TESTED ON BOARD)
2026-06-19 Corrected bug with N-Mosfet
    [monitor_lamp_custom_pcb.kicad_pcb, untitled.kicad_sch]
2026-07-04 Enhance README with PCB updates and new images
    Updated the README to include new images and details about the custom PCB design, corrections made, and the overall functionality of the system.
